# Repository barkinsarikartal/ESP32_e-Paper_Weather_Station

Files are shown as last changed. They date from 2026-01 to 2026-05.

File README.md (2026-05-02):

# ESP32 e-Paper Weather Station

A low-power, minimalist weather station powered by ESP32 and a Waveshare 1.54" e-Paper display. This project fetches real-time weather data from the OpenWeatherMap API and displays it on a crisp, tri-color (Red/Black/White) e-Ink screen.

<div align="center">
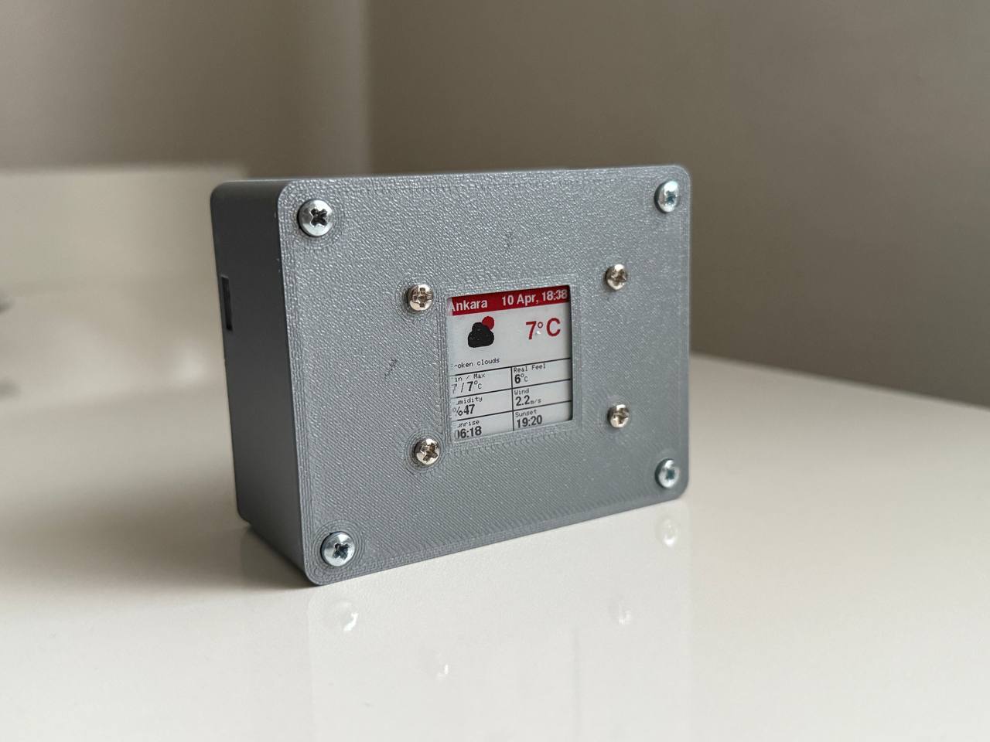
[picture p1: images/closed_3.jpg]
Project Showcase
  
</div>

## Features

* **Tri-Color Display:** Utilizes the red, black, and white capabilities of the Waveshare e-Paper module for a distinct, high-contrast UI.
* **Deep Sleep Power Saving:** The device wakes up, updates the screen, and immediately enters deep sleep to maximize battery life.
    * **Success Cycle:** Updates every 4 hours.
    * **Error Cycle:** Retries in 10 minutes if Wi-Fi or API fails (screen content is preserved to avoid displaying error messages permanently).
* **Comprehensive Data:** Displays City, Date, Time, Temperature, Weather Condition, Min/Max Temp, Real Feel, Humidity, Wind Speed, Sunrise, and Sunset times.
* **Custom Icons:** Includes custom-designed, pixel-perfect weather icons.

## Hardware Requirements

* **Microcontroller:** ESP32 (Tested on ESP32-WROOM-32U and Seeed Studio XIAO ESP32C3)
* **Display:** Waveshare 1.54inch e-Paper Module (B) V2 (SSD1680 Driver)
* **Connection:** SPI Interface

## Optional: 3D Printed Enclosure

To use this project with its custom 3D printed enclosure, you will need the following additional materials:
* **Charger IC:** TP4056 with Type-C Connection *(Not needed if using XIAO ESP32C3)*
* **Battery:** 18650 Li-ion Rechargable Battery (With a Single Cell Battery Holder)
* **Step-Up Boost Converter:** MT3608 Adjustable DC-DC Boost Power Converter *(Not needed if using XIAO ESP32C3)*
* **Hardware:** 4x M3x5.75 Brass Inserts, 4x M3 Screws Up to 8mm in Length

> **Note:** The brass inserts must be inserted into the 3D printed box using a soldering iron. Double-sided tape was used to secure the components inside the box.
> 
> **Important for XIAO ESP32C3 Users:** The XIAO ESP32C3 has a built-in battery charging circuit. You can connect your 18650 battery directly to the `BAT+` and `BAT-` pads on the bottom of the XIAO. Because of this, you do NOT need the TP4056 or MT3608 modules!
>
> **Battery Status:** There is currently no battery level measurement in this project. I started with a fully charged 1500 mAh 18650 battery. It lasted exactly a week with ESP32-WROOM-32U. I have not tested it with XIAO ESP32C3 yet. You can check if the battery is fully charged by observing the TP4056 LEDs visible through the Type-C port gap: when the red LED turns off and the blue LED turns on, the battery is fully charged.

The 3D models were designed using OpenSCAD with the help of Google Gemini. You can find the 3D files in the `/3D` folder of this repository, which includes:
* `box.scad` / `box.stl`: The main body/box of the enclosure.
* `lid.scad` / `lid.stl`: The front cover/lid of the enclosure.
* `print.3mf`: A ready-to-print project file containing both parts.

Alternatively, you can check them out and download them directly from [MakerWorld](https://makerworld.com/tr/models/2665507-weather-station-with-esp32-and-waveshare-e-paper#profileId-2949378).

Before Connecting Components to the 3D Box:
<div align="center">
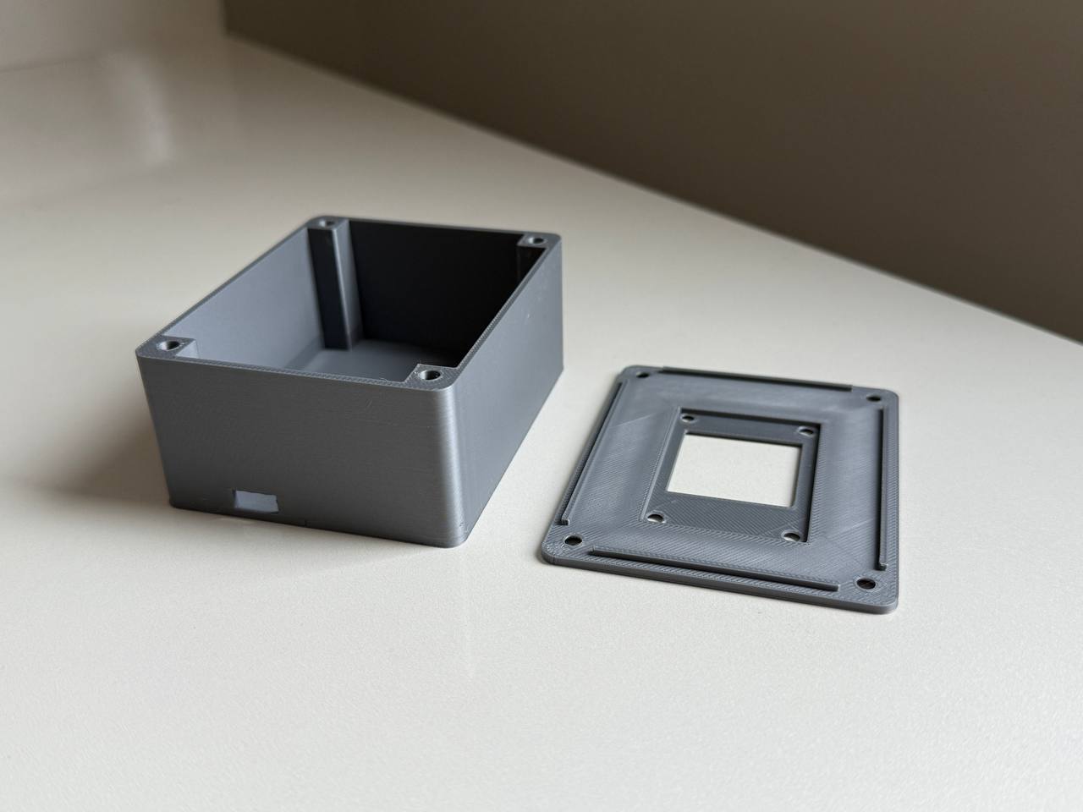
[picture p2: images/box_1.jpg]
  
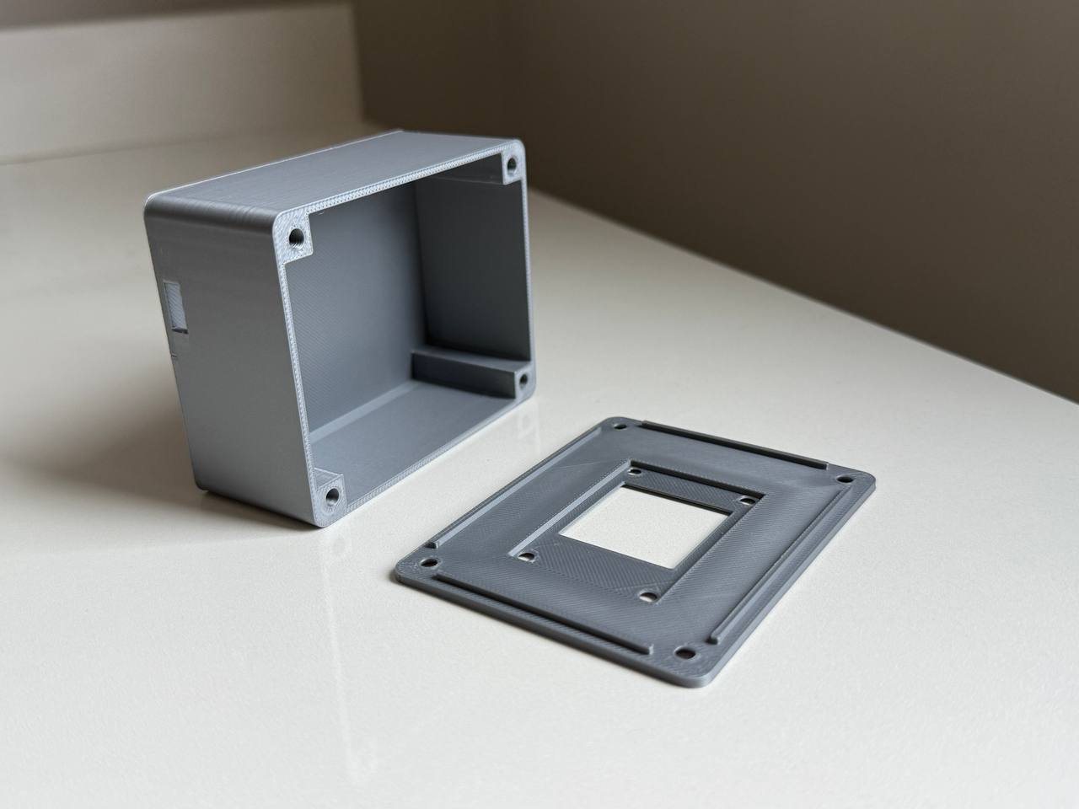
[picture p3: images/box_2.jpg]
  
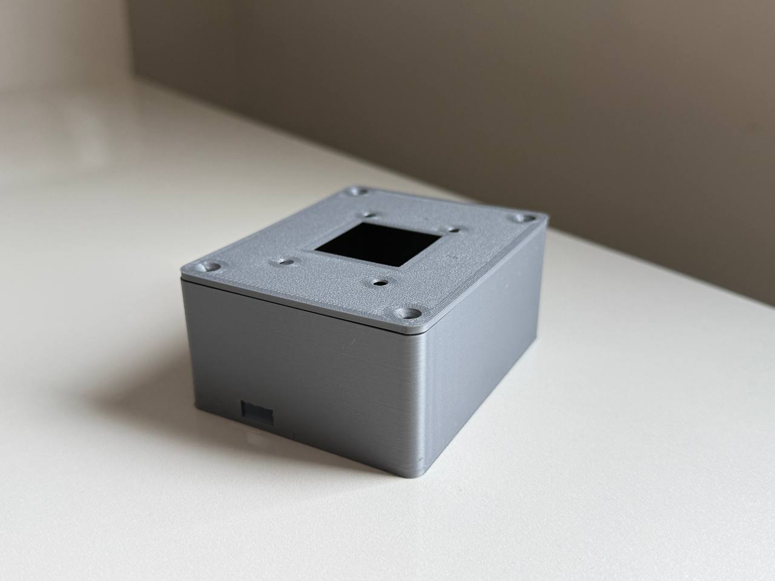
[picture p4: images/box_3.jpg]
  
</div>
<div align="center">
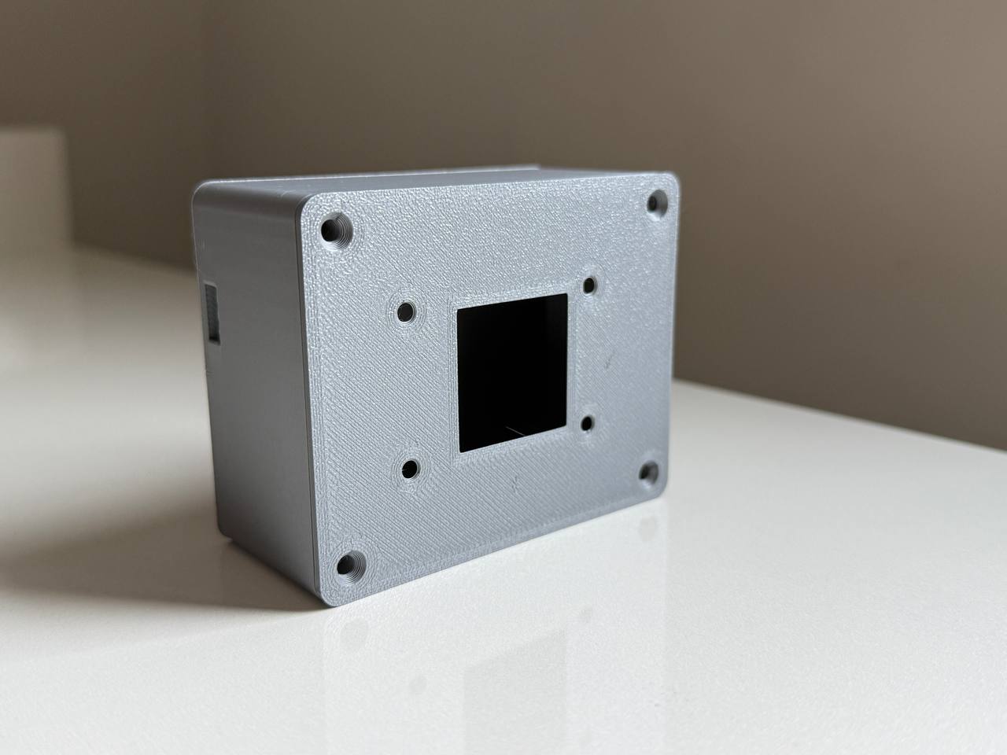
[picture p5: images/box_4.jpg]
  
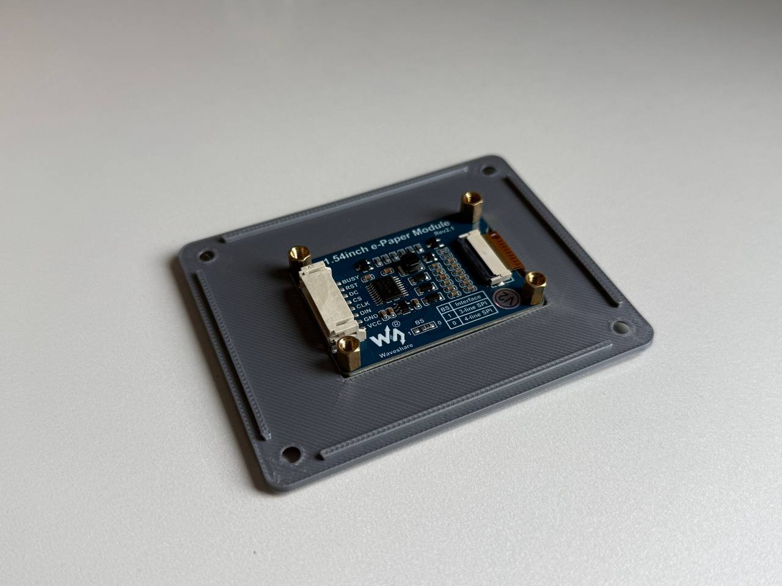
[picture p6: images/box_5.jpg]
  
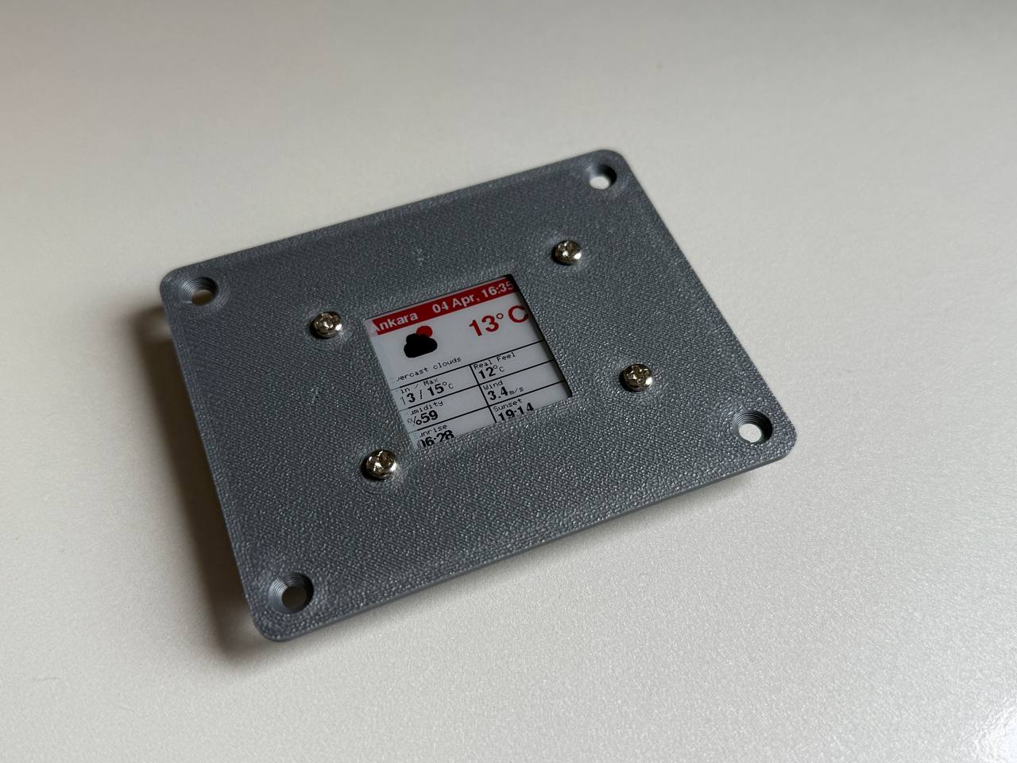
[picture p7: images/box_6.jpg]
  
</div>

<br>

After Connecting Components to the 3D Box:
<div align="center">
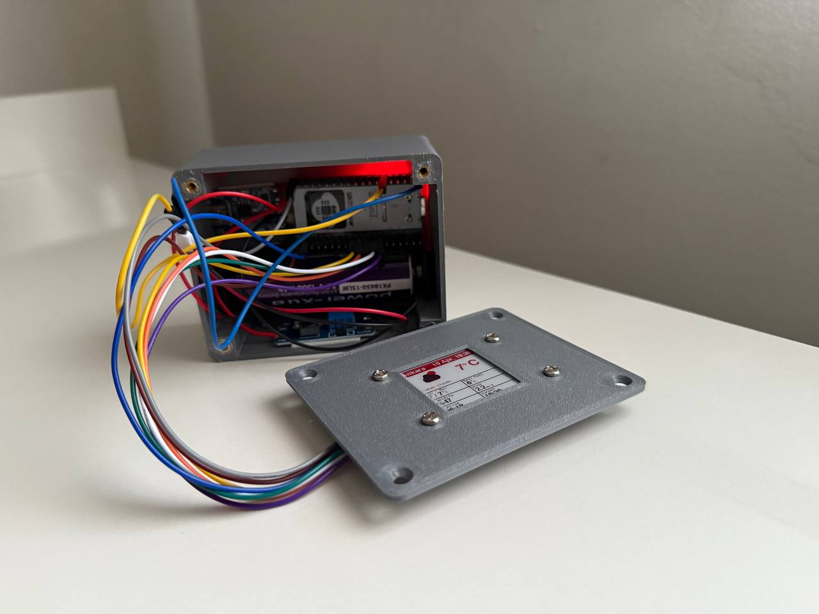
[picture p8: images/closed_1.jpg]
  
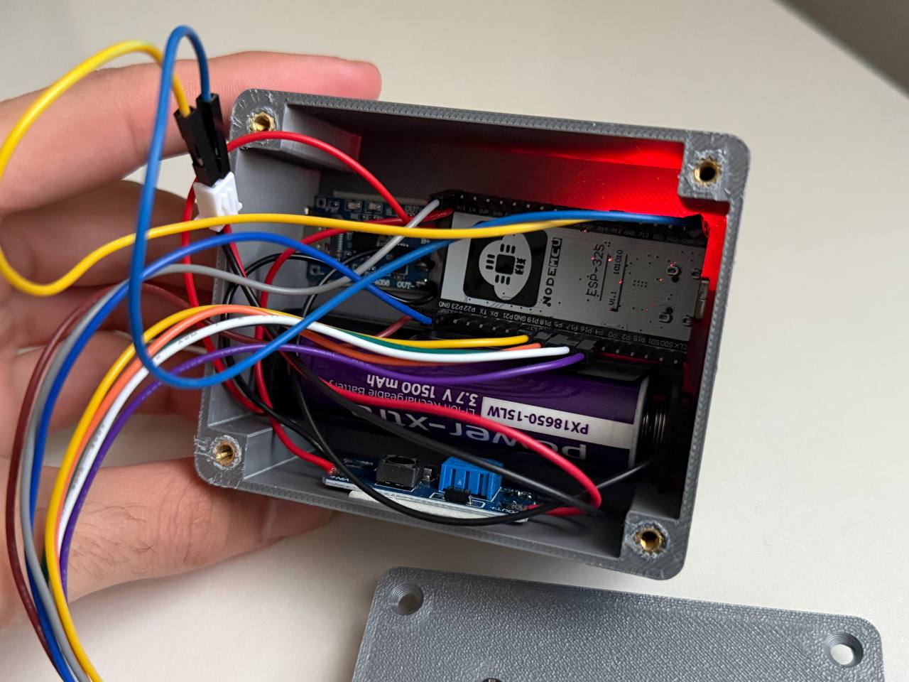
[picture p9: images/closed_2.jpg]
  
</div>
<div align="center">
  
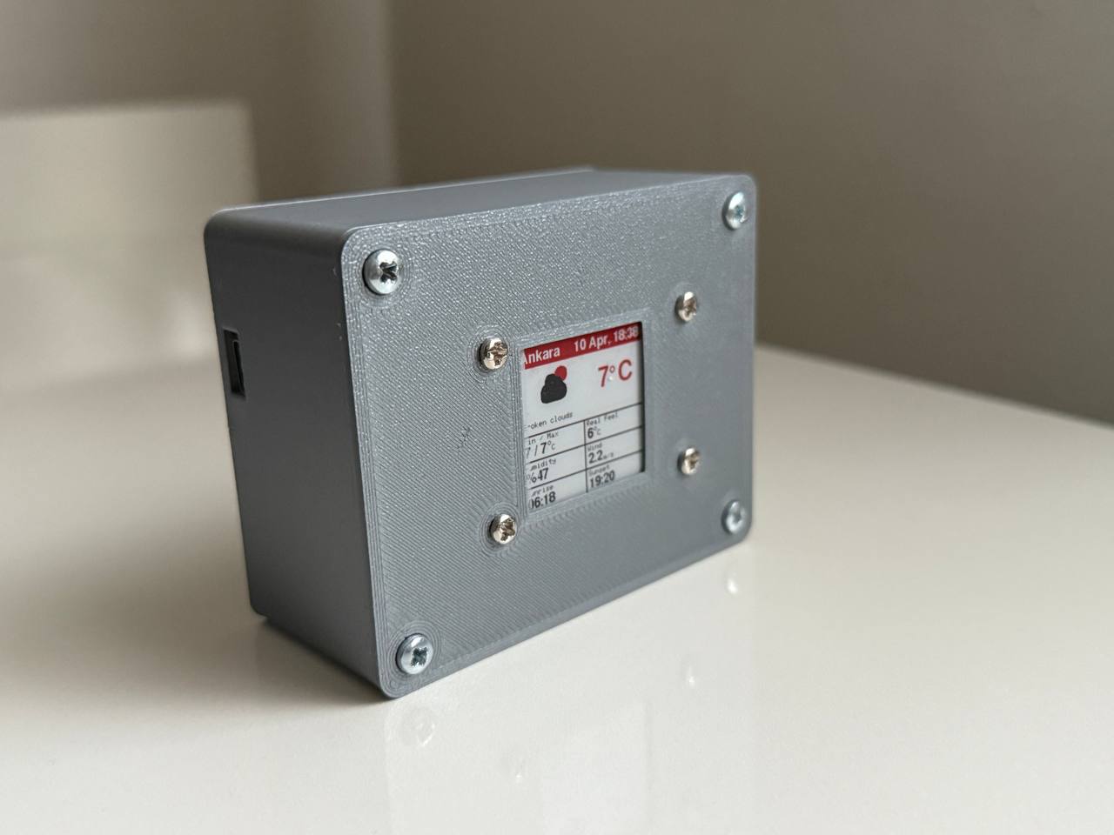
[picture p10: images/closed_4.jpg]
  
</div>

## Wiring Diagram

Connect the e-Paper HAT to your chosen microcontroller as defined in `config.h`. 

### Option A: ESP32-WROOM-32U

<div align="center">
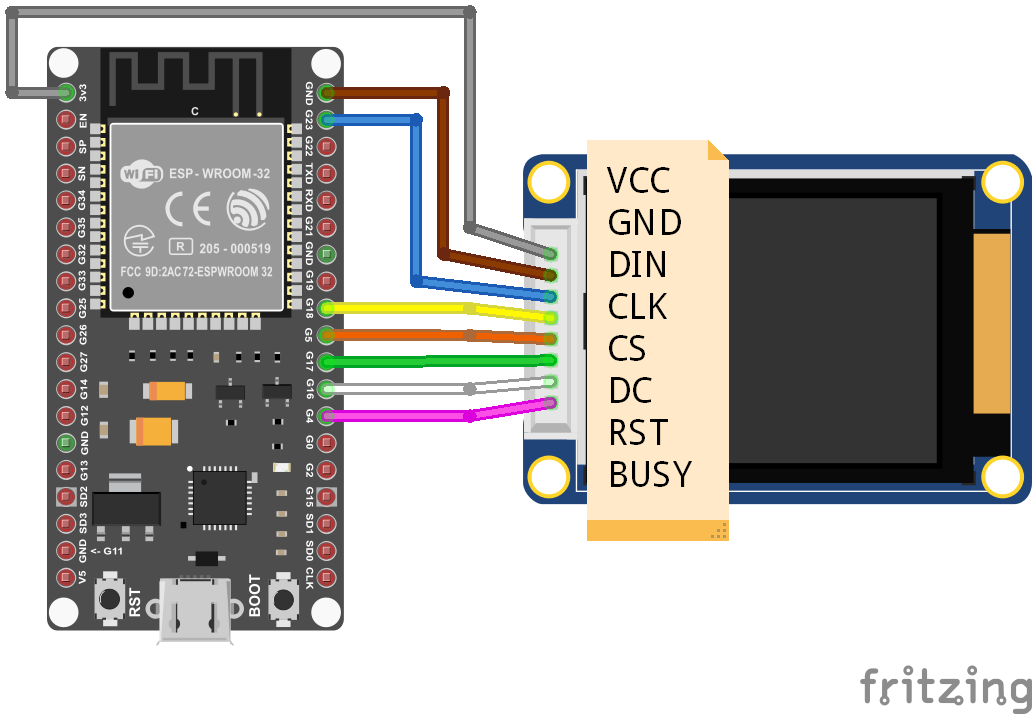
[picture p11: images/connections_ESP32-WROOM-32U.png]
ESP32-WROOM-32U Wiring Diagram
  
</div>

<br>

<div align="center">
  <table>
    <tr><th>e-Paper Pin</th><th>ESP32 Pin</th><th>Function</th></tr>
    <tr><td><b>VCC</b></td><td><b>3.3V</b></td><td>Power</td></tr>
    <tr><td><b>GND</b></td><td><b>GND</b></td><td>Ground</td></tr>
    <tr><td><b>DIN</b></td><td><b>GPIO 23</b></td><td>MOSI</td></tr>
    <tr><td><b>CLK</b></td><td><b>GPIO 18</b></td><td>SCK</td></tr>
    <tr><td><b>CS</b></td><td><b>GPIO 5</b></td><td>Chip Select</td></tr>
    <tr><td><b>DC</b></td><td><b>GPIO 17</b></td><td>Data/Cmd</td></tr>
    <tr><td><b>RST</b></td><td><b>GPIO 16</b></td><td>Reset</td></tr>
    <tr><td><b>BUSY</b></td><td><b>GPIO 4</b></td><td>Busy Status</td></tr>
  </table>
</div>

### Option B: Seeed Studio XIAO ESP32C3

<div align="center">
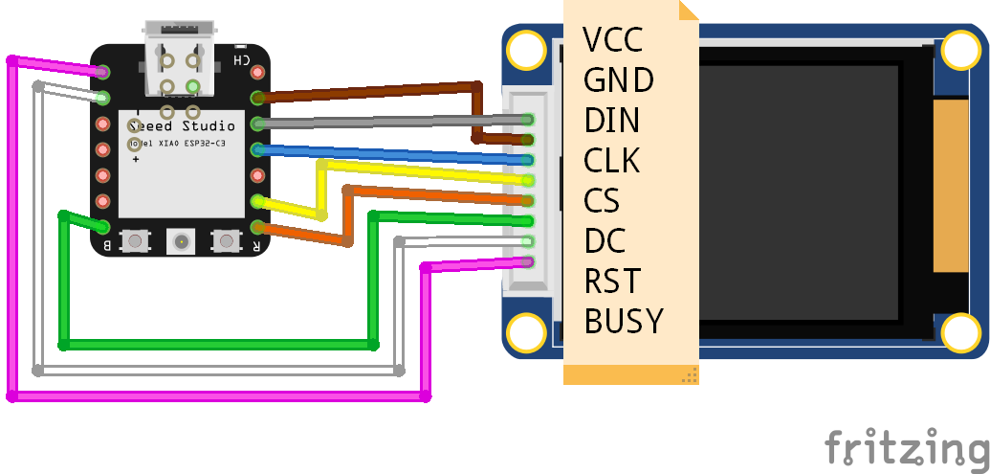
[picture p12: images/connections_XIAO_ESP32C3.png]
XIAO ESP32C3 Wiring Diagram
  
</div>

<br>

<div align="center">
  <table>
    <tr><th>e-Paper Pin</th><th>XIAO ESP32C3 Pin</th><th>Function</th></tr>
    <tr><td><b>VCC</b></td><td><b>3.3V</b></td><td>Power</td></tr>
    <tr><td><b>GND</b></td><td><b>GND</b></td><td>Ground</td></tr>
    <tr><td><b>DIN</b></td><td><b>GPIO 10 (D10)</b></td><td>MOSI</td></tr>
    <tr><td><b>CLK</b></td><td><b>GPIO 8 (D8)</b></td><td>SCK</td></tr>
    <tr><td><b>CS</b></td><td><b>GPIO 20 (D7)</b></td><td>Chip Select</td></tr>
    <tr><td><b>DC</b></td><td><b>GPIO 21 (D6)</b></td><td>Data/Cmd</td></tr>
    <tr><td><b>RST</b></td><td><b>GPIO 3 (D1)</b></td><td>Reset</td></tr>
    <tr><td><b>BUSY</b></td><td><b>GPIO 2 (D0)</b></td><td>Busy Status</td></tr>
  </table>
</div>

## Dependencies

This project requires the following Arduino libraries:

* **GxEPD2** by Jean-Marc Zingg (Display Driver)
* **Adafruit GFX Library** (Graphics Core)
* **ArduinoJson** by Benoit Blanchon (JSON Parsing)
* **HTTPClient** (Built-in ESP32 lib)
* **WiFi** (Built-in ESP32 lib)

## Configuration

1.  **Clone the repository:**
    ```bash
    git clone https://github.com/barkinsarikartal/ESP32_e-Paper_Weather_Station.git
    ```
2.  **Select Your Board:** Open `ESP32_e-Paper_Weather_Station.ino` and uncomment the board you are using at the top of the file:
    ```cpp
    // #define BOARD_ESP32_DEVKIT
    // #define BOARD_XIAO_ESP32C3
    ```
3.  **Update Credentials:** Open `config.h` and update your Wi-Fi and OpenWeatherMap details:
    ```cpp
    // config.h
    const char* WIFI_SSID = "YOUR_WIFI_SSID";
    const char* WIFI_PASS = "YOUR_WIFI_PASSWORD";
    
    // Get your free API key from https://openweathermap.org/
    String OPENWEATHER_URL = "https://api.openweathermap.org/data/2.5/weather?q=CITY,COUNTRY&units=metric&appid=YOUR_API_KEY"; 
    ```
4.  **Upload:** Connect your ESP32 via USB and upload the code using the Arduino IDE.

## File Structure

* `ESP32_e-Paper_Weather_Station.ino`: Main application logic, deep sleep management, UI rendering, and board selection.
* `config.h`: Configuration file for Wi-Fi credentials, API endpoints, pin definitions, and sleep timers.
* `bitmaps.h`: Contains byte arrays for the custom weather icons (Sun, Clouds, Rain, Snow, etc.).
* `sketch_ESP32-WROOM-32U.fzz` & `sketch_XIAO_ESP32C3.fzz`: Fritzing wiring diagrams for both boards.

## Power Consumption Logic

To ensure longevity, the code implements a "Silent Fail" mechanism:
* **If Data Fetched:** The screen updates, and the ESP32 sleeps for **4 hours**.
* **If Connection Fails:** The screen **is not updated** (preserving the last known good weather data), and the ESP32 sleeps for only **10 minutes** before retrying.

## License

This project is open-source and available under the MIT License.

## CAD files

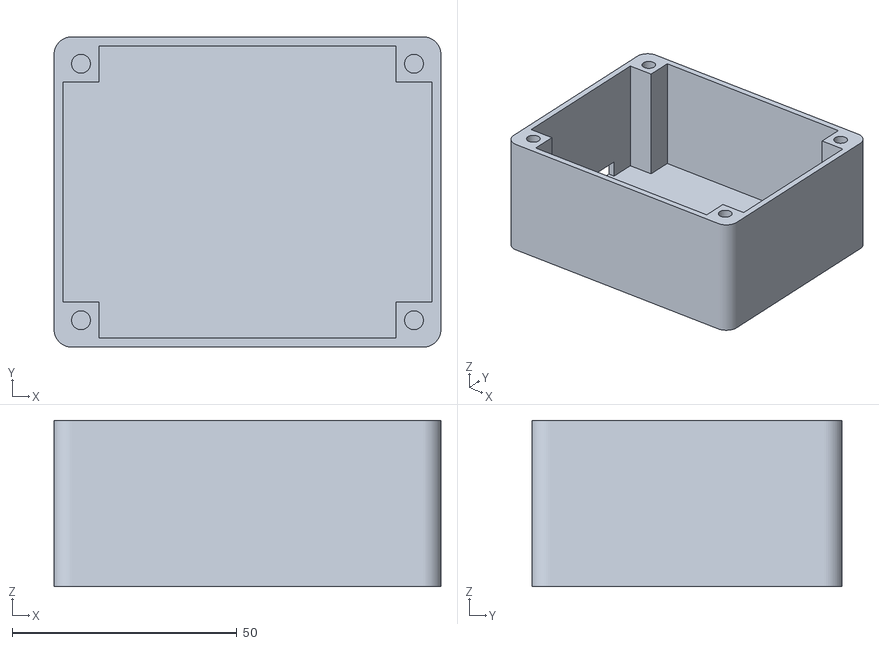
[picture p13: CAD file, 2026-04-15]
3D/box.stl
86.0 x 69.0 x 37.0

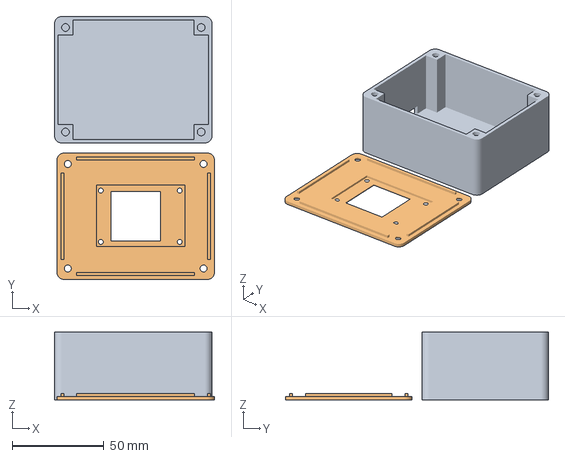
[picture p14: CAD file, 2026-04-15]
3D/print.3mf
87.3 x 143.4 x 37.0 mm
box.stl
lid.stl

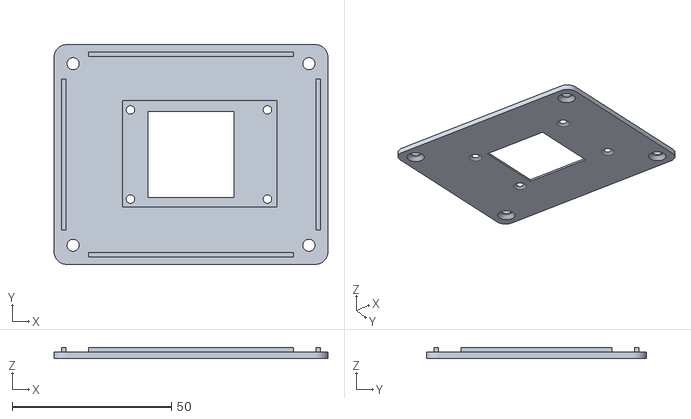
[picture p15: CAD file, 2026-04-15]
3D/lid.stl
86.0 x 69.0 x 3.50

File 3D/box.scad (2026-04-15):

// --- PARAMETRELER ---
$fn = 60;
wall = 2.0;
internal_w = 82;
internal_h = 65;
internal_d = 35;
clearance = 0.5;
box_radius = 4.0;

// Kılavuz Kenarı (Lip) Parametreleri
lip_height = 1.5;     // Kapağın içine doğru giren çıkıntı
lip_clearance = 0.3;  // Rahat geçmesi için bırakılan tolerans

// Köşe Sütunları
pillar_s = 8;
insert_dia = 4.2;
insert_depth = 8; 

// Ekran Montajı (Waveshare 1.54")
disp_pcb_w = 48;
disp_pcb_h = 33;
disp_pattern_x = 43;
disp_pattern_y = 28;

// Delik Çapları
disp_screw_hole = 0.0; // M3 vidanın geçmesi için
disp_countersink = 5.0; // M3 vida başı için

// --- YARDIMCI MODÜL: Yuvarlatılmış Dikdörtgen ---
module rounded_box(w, h, d, r) {
    hull() {
        translate([r, r, 0]) cylinder(r=r, h=d);
        translate([w-r, r, 0]) cylinder(r=r, h=d);
        translate([r, h-r, 0]) cylinder(r=r, h=d);
        translate([w-r, h-r, 0]) cylinder(r=r, h=d);
    }
}

module body() {
    difference() {
        // Dış Kabuk (Yuvarlatılmış)
        rounded_box(internal_w + 2*wall, internal_h + 2*wall, internal_d + wall, box_radius);
        
        translate([wall, wall, wall])
            rounded_box(internal_w, internal_h, internal_d + 1, box_radius - wall);
        
        // USB-C Kesimi
        translate([-1, 39 + wall, wall])
            cube([wall + 2, 10, 5]);
    }

    for(pos = [[wall, wall], 
               [internal_w + wall - pillar_s, wall], 
               [internal_w + wall - pillar_s, internal_h + wall - pillar_s], 
               [wall, internal_h + wall - pillar_s]]) {
        translate([pos[0], pos[1], wall])
        difference() {
            cube([pillar_s, pillar_s, internal_d]);
            translate([pillar_s/2, pillar_s/2, internal_d - insert_depth])
                cylinder(d=insert_dia, h=insert_depth + 1);
        }
    }
}

body();

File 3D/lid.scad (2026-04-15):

// --- PARAMETRELER ---
$fn = 60;
wall = 2.0;
internal_w = 82;
internal_h = 65;
internal_d = 35;
clearance = 0.5;
box_radius = 4.0;

// Kılavuz Kenarı (Lip) Parametreleri
lip_height = 1.5;     // Kapağın içine doğru giren çıkıntı
lip_clearance = 0.3;  // Rahat geçmesi için bırakılan tolerans

// Köşe Sütunları
pillar_s = 8;
insert_dia = 4.2;
insert_depth = 8; 

// Ekran Montajı (Waveshare 1.54")
disp_pcb_w = 48;
disp_pcb_h = 33;
disp_pattern_x = 43;
disp_pattern_y = 28;

// Delik Çapları
disp_screw_hole = 0.0; // M3 vidanın geçmesi için
disp_countersink = 5.0; // M3 vida başı için

// --- YARDIMCI MODÜL: Yuvarlatılmış Dikdörtgen ---
module rounded_box(w, h, d, r) {
    hull() {
        translate([r, r, 0]) cylinder(r=r, h=d);
        translate([w-r, r, 0]) cylinder(r=r, h=d);
        translate([r, h-r, 0]) cylinder(r=r, h=d);
        translate([w-r, h-r, 0]) cylinder(r=r, h=d);
    }
}

module lid() {
    window_size = 27;
    // Pencere konumu
    win_x = (internal_w + 2*wall - window_size) / 2;
    win_y = (internal_h + 2*wall - window_size) / 2;

    // Ekranın PCB'sinin oturacağı toplam alan (Gömme alanı)
    pocket_w = disp_pcb_w + 0.5;
    pocket_h = disp_pcb_h + 0.5;
    // PCB'nin kapağa göre konumu (Offsetler dahil)
    pocket_x = win_x - 8; 
    pocket_y = win_y - 3;
    
    standoff_base_x = win_x - 8 + (disp_pcb_w - disp_pattern_x)/2;
    standoff_base_y = win_y - 3 + (disp_pcb_h - disp_pattern_y)/2;

    difference() {
        // Ana Kapak Plakası
        rounded_box(internal_w + 2*wall, internal_h + 2*wall, wall, box_radius);
        
        translate([pocket_x, pocket_y, wall - 1.3])
            cube([pocket_w, pocket_h, 1.4]);

        // Ekran Penceresi (Dışarıya açılan delik)
        translate([win_x, win_y, -1])
            cube([window_size, window_size, wall + 2]);
        
        // Havşalı Vida Delikleri (M3)
        for(pos = [[wall + pillar_s/2, wall + pillar_s/2], 
                   [internal_w + wall - pillar_s/2, wall + pillar_s/2], 
                   [internal_w + wall - pillar_s/2, internal_h + wall - pillar_s/2], 
                   [wall + pillar_s/2, internal_h + wall - pillar_s/2]]) {
            translate([pos[0], pos[1], -1]) {
                cylinder(d=3.8, h=wall + 2);
                translate([0,0, 0.9]) 
                    cylinder(d1=7.0, d2=3.8, h=1.5);
            }
        }
        
        // Ekran Sabitleme Vidaları (Dışarıdan atılacak delikler)
        for(x = [0, disp_pattern_x], y = [0, disp_pattern_y]) {
            translate([standoff_base_x + x, standoff_base_y + y, -1]) {
                // Vida geçiş deliği
                cylinder(d=disp_screw_hole, h=wall + 2);
                // Dış yüzeydeki havşa deliği (Vida başı sıfır olması için)
                translate([0, 0, 1.0]) 
                    cylinder(d1=disp_countersink, d2=disp_screw_hole, h=1.5);
            }
        }
    }
    
    // Kılavuz Kenarı
    translate([wall + lip_clearance, wall + lip_clearance, wall])
    difference() {
        // Ana Kılavuz Çerçevesi
        rounded_box(internal_w - 2*lip_clearance, internal_h - 2*lip_clearance, lip_height, box_radius - wall - lip_clearance);
        
        // Çerçevenin içini boşalt (Sadece bir kenar kalsın)
        translate([1.5, 1.5, -1])
            rounded_box(internal_w - 2*lip_clearance - 3, internal_h - 2*lip_clearance - 3, lip_height + 2, box_radius - wall - lip_clearance - 1.5);
            
        // Köşe Sütunları için Boşluklar (Kılavuz kenarı sütunlara çarpmamalı)
        pillar_clearance = 0.5;
        for(pos = [[-1, -1], 
                   [internal_w - pillar_s - 2*lip_clearance - pillar_clearance, -1], 
                   [internal_w - pillar_s - 2*lip_clearance - pillar_clearance, internal_h - pillar_s - 2*lip_clearance - pillar_clearance], 
                   [-1, internal_h - pillar_s - 2*lip_clearance - pillar_clearance]]) {
            translate([pos[0], pos[1], -0.1])
                cube([pillar_s + pillar_clearance + 1, pillar_s + pillar_clearance + 1, lip_height + 1]);
        }
    }

}

lid();

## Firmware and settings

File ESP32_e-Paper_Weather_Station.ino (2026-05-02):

/**
 * ESP32 e-Paper Weather Station
 * Hardware: ESP32-WROOM-32U + Waveshare 1.54" V2 (SSD1680)
 * Source: OpenWeatherMap API
 * Notes: Please do not forget to change WiFi Credentials and OpenWeather API URL from config.h
 */

// Select a board for your project. Remove the // symbol at the beginning of the board you are using:
// #define BOARD_ESP32_DEVKIT
// #define BOARD_XIAO_ESP32C3

#include <GxEPD2_3C.h>
#include <Fonts/FreeSansBold9pt7b.h>
#include <Fonts/FreeSansBold12pt7b.h>
#include <Fonts/FreeSansBold18pt7b.h>
#include <WiFi.h>
#include <HTTPClient.h>
#include <ArduinoJson.h>
#include <time.h>

#include "config.h"
#include "bitmaps.h"

// Display Constructor for Waveshare 1.54" V2 (https://www.waveshare.com/1.54inch-e-paper-module-b.htm)
GxEPD2_3C<GxEPD2_154_Z90c, GxEPD2_154_Z90c::HEIGHT> display(GxEPD2_154_Z90c(EPD_CS, EPD_DC, EPD_RST, EPD_BUSY));

// Data Holders
String cityName, country, weatherDesc, iconCode;
float temp, feelsLike, tempMin, tempMax, windSpeed;
int humidity;
long dt, sunrise, sunset;
int timezone;
bool dataFetched = false;

// Function Prototypes
void fetchWeatherData();
void drawDashboardUI();
void drawLabelValue(int x, int y, String label, String value);
void drawOWMIcon(String code, int x, int y, int h, int w);
String getFormattedTime(long unixTime, int timezoneOffset);
String getFormattedDate(long unixTime, int timezoneOffset);

void setup() {
  Serial.begin(115200);
  
  // 1. Connect to WiFi
  // We try to connect. If it fails, we won't even turn on the display.
  WiFi.begin(WIFI_SSID, WIFI_PASS);
  int timeout = 0;
  Serial.print("Connecting to WiFi");
  while (WiFi.status() != WL_CONNECTED && timeout < 20) {
    delay(500);
    Serial.print(".");
    timeout++;
  }
  Serial.println();
  
  // 2. Try Fetching Data
  if (WiFi.status() == WL_CONNECTED) {
    Serial.println("WiFi connected. Fetching data...");
    fetchWeatherData();

    // Disconnect WiFi to save power immediately after fetching
    WiFi.disconnect(true);
    WiFi.mode(WIFI_OFF);
  }
  else {
    Serial.println("WiFi connection failed.");
  }

  // 3. Decision Logic
  uint64_t sleepTimer;
  
  if (dataFetched) {
    Serial.println("Data fetched successfully. Updating display.");

    SPI.begin(SPI_SCK, SPI_MISO, SPI_MOSI, EPD_CS);
    display.init(115200);
    display.setRotation(1);

    drawDashboardUI();

    display.powerOff();

    sleepTimer = SLEEP_DURATION_OK; // 4 Hours
  }
  else {
    Serial.println("Failed to fetch data. Keeping old screen content.");
    Serial.println("Going to short sleep.");

    // The e-Paper will keep showing whatever was on it before (the old weather data).
    sleepTimer = SLEEP_DURATION_ERROR; // 10 Minutes
  }

  // 4. Enter Deep Sleep
  Serial.printf("Entering deep sleep for %llu microseconds...\n", sleepTimer);
  esp_sleep_enable_timer_wakeup(sleepTimer);
  esp_deep_sleep_start();
}

void loop() {
  //empty loop - unreachable
  Serial.println("if you are seeing this on serial monitor, something went wrong...");
  delay(1000);
}

void fetchWeatherData() {
  HTTPClient http;
  http.begin(OPENWEATHER_URL);
  int httpCode = http.GET();

  if (httpCode > 0) {
    String payload = http.getString();
    Serial.println(payload);
    DynamicJsonDocument doc(2048);
    DeserializationError error = deserializeJson(doc, payload);

    if (!error) {
      cityName = doc["name"].as<String>();
      weatherDesc = doc["weather"][0]["description"].as<String>();
      iconCode = doc["weather"][0]["icon"].as<String>();
      country = doc["sys"]["country"].as<String>();
      
      temp = doc["main"]["temp"];
      feelsLike = doc["main"]["feels_like"];
      tempMin = doc["main"]["temp_min"];
      tempMax = doc["main"]["temp_max"];
      humidity = doc["main"]["humidity"];
      windSpeed = doc["wind"]["speed"];
      
      dt = doc["dt"];
      sunrise = doc["sys"]["sunrise"];
      sunset = doc["sys"]["sunset"];
      timezone = doc["timezone"];
      
      if (weatherDesc.length() > 0) {
        weatherDesc.setCharAt(0, toupper(weatherDesc.charAt(0)));
      }
      
      dataFetched = true;
    }
    else {
      Serial.print("JSON Error: "); Serial.println(error.c_str());
    }
  }
  else {
    Serial.printf("HTTP Error: %s\n", http.errorToString(httpCode).c_str());
  }
  http.end();
}

void drawDashboardUI() {
  display.setFullWindow();
  display.firstPage();
  do {
    display.fillScreen(GxEPD_WHITE);

    // Header
    display.fillRect(0, 0, 200, 25, GxEPD_RED);
    display.setTextColor(GxEPD_WHITE);
    display.setFont(&FreeSansBold9pt7b);
    display.setCursor(5, 18);
    display.print(cityName);

    String dateStr = getFormattedDate(dt, timezone);
    String timeStr = getFormattedTime(dt, timezone);
    String headerRight = dateStr + ", " + timeStr;

    int16_t x1, y1; uint16_t w, h;
    display.getTextBounds(headerRight, 0, 0, &x1, &y1, &w, &h);
    display.setCursor(200 - w - 5, 18);
    display.print(headerRight);

    // Main Icon & Temp
    drawOWMIcon(iconCode, 18, 19, 75, 75);

    display.setTextColor(GxEPD_RED);
    display.setFont(&FreeSansBold18pt7b);
    String tempNum = String((int)temp);
    display.getTextBounds(tempNum, 0, 0, &x1, &y1, &w, &h);
    int centerX = 90 + (110 - w) / 2; 
    display.setCursor(centerX - 10, 70);
    display.print(tempNum);
    
    // Manual Degree Symbol and "C"
    int circleX = display.getCursorX() + 5;
    int circleY = 70 - 18;
    display.drawCircle(circleX, circleY, 4, GxEPD_RED);
    display.drawCircle(circleX, circleY, 3, GxEPD_RED);
    display.setCursor(circleX + 10, 70);
    display.print("C");

    display.setTextColor(GxEPD_BLACK);
    display.setFont(NULL);
    display.setCursor(5, 90); 
    display.print(weatherDesc);

    // Grid
    display.fillRect(0, 105, 200, 2, GxEPD_BLACK);
    display.fillRect(0, 136, 200, 2, GxEPD_BLACK);
    display.fillRect(0, 168, 200, 2, GxEPD_BLACK);
    display.fillRect(100, 105, 2, 95, GxEPD_BLACK);

    display.setTextColor(GxEPD_BLACK);
    drawLabelValue(5, 108, "Min / Max", String((int)tempMin) + " / " + String((int)tempMax));
    drawLabelValue(105, 108, "Real Feel", String((int)feelsLike));
    drawLabelValue(5, 140, "Humidity", "%" + String(humidity));
    drawLabelValue(105, 140, "Wind", String(windSpeed, 1));
    drawLabelValue(5, 172, "Sunrise", getFormattedTime(sunrise, timezone));
    drawLabelValue(105, 172, "Sunset", getFormattedTime(sunset, timezone));
  }
  while (display.nextPage());
}

void drawLabelValue(int x, int y, String label, String value) {
  display.setFont(NULL);
  display.setCursor(x, y); display.print(label);
  display.setFont(&FreeSansBold9pt7b);
  int yValue = y + 22;
  display.setCursor(x, yValue); display.print(value);
  
  // Degree Symbol and "C" for Real Feel
  if(label == "Real Feel") {
    int cx = display.getCursorX() + 3;
    int cy = yValue - 10;
    display.drawCircle(cx, cy, 2, GxEPD_BLACK);
    display.setFont(NULL);
    display.setCursor(cx + 4, yValue - 7);
    display.print("C");
  }
  
  // Degree Symbol and "C" for Min/Max
  else if(label == "Min / Max") {
    int cx = display.getCursorX() + 3;
    int cy = yValue - 10;
    display.drawCircle(cx, cy, 2, GxEPD_BLACK);
    display.setFont(NULL);
    display.setCursor(cx + 4, yValue - 7);
    display.print("C");
  }

  // Unit for Wind
  else if(label == "Wind") {
    display.setFont(NULL);
    display.setCursor(display.getCursorX() + 2, yValue - 5);
    display.print("m/s");
  }
}

String getFormattedTime(long unixTime, int timezoneOffset) {
  time_t localTime = unixTime + timezoneOffset; 
  struct tm * ti = gmtime(&localTime);
  char buffer[6];
  sprintf(buffer, "%02d:%02d", ti->tm_hour, ti->tm_min);
  return String(buffer);
}

String getFormattedDate(long unixTime, int timezoneOffset) {
  time_t localTime = unixTime + timezoneOffset;
  struct tm * ti = gmtime(&localTime);
  char buffer[10];
  strftime(buffer, sizeof(buffer), "%d %b", ti);
  return String(buffer);
}

void drawOWMIcon(String code, int x, int y, int h, int w) { // based on https://openweathermap.org/weather-conditions
  bool isNight = (code.indexOf('n') != -1);
  String mainCode = code.substring(0, 2);

  if (mainCode == "01") { // Clear Sky
    if (isNight) display.drawBitmap(x, y, moon, h, w, GxEPD_BLACK);
    else display.drawBitmap(x, y, sun, h, w, GxEPD_RED);
  }
  else if (mainCode == "02" || mainCode == "03" || mainCode == "04") { // Few/Scattered/Broken Clouds
    if (!isNight){
      display.drawBitmap(x, y, clouds, h, w, GxEPD_BLACK);
      display.drawBitmap(x, y, sun_over_clouds, h, w, GxEPD_RED);
    }
    else {
      display.drawBitmap(x, y, clouds, h, w, GxEPD_BLACK);
      display.drawBitmap(x, y, moon_over_clouds, h, w, GxEPD_BLACK);
    }
  } 
  else if (mainCode == "09" || mainCode == "10") { // Rain
    display.drawBitmap(x, y, rainy, h, w, GxEPD_BLACK);
  } 
  else if (mainCode == "11") { // Thunderstorm
    display.drawBitmap(x, y, thunder, h, w, GxEPD_BLACK);
  } 
  else if (mainCode == "13") { // Snow
    display.drawBitmap(x, y, snow, 50, 50, GxEPD_BLACK);
  } 
  else if (mainCode == "50") { // Mist
    display.drawBitmap(x, y, fog, h, w, GxEPD_BLACK);
  }
  else { // Unknown
    display.drawCircle(x, y, 15, GxEPD_BLACK);
    display.setCursor(x-5, y+5); display.print("?");
  }
}

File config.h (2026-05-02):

#ifndef CONFIG_H
#define CONFIG_H

// --- Wi-Fi Credentials ---
const char* WIFI_SSID = "WIFI_SSID";
const char* WIFI_PASS = "WIFI_PASS";

// --- OpenWeatherMap Settings ---
// Zip code is generally more accurate than city name alone
// More information at: https://openweathermap.org/current

// For zip code queries
// ZZZZZ = Zip Code, CC = Country (e.g. TR, GB), ABCDEFGHIJKLMNOPQRSTUVWXYZ= = Your API Key
// String OPENWEATHER_URL = "https://api.openweathermap.org/data/2.5/weather?zip=ZZZZZ,CC&units=metric&appid=ABCDEFGHIJKLMNOPQRSTUVWXYZ";

// For city queries
// AAA = City (e.g. Ankara, London), CC = Country (e.g. TR, GB), ABCDEFGHIJKLMNOPQRSTUVWXYZ= = Your API Key
String OPENWEATHER_URL = "https://api.openweathermap.org/data/2.5/weather?q=AAA,CC&units=metric&appid=ABCDEFGHIJKLMNOPQRSTUVWXYZ";

// --- Pin Definitions (ESP32 -> Waveshare e-Paper Driver Hat) ---
#if defined(BOARD_ESP32_DEVKIT)
  // NodeMCU-ESP32S / ESP32-WROOM-32U
  #define EPD_CS    5
  #define EPD_DC    17
  #define EPD_RST   16
  #define EPD_BUSY  4
  #define SPI_SCK   18
  #define SPI_MISO  19
  #define SPI_MOSI  23

#elif defined(BOARD_XIAO_ESP32C3)
  // Seeed Studio XIAO ESP32-C3
  #define EPD_CS    20   // D7
  #define EPD_DC    21   // D6
  #define EPD_RST   3    // D1
  #define EPD_BUSY  2    // D0
  #define SPI_SCK   8    // D8
  #define SPI_MISO  9    // D9
  #define SPI_MOSI  10   // D10

#else
  #error "No board selected! Select a BOARD_ definition in the config.h file."
#endif

// --- Sleep Intervals (in microseconds) ---
// 4 Hours = 4 * 60 * 60 * 1,000,000
const uint64_t SLEEP_DURATION_OK = 14400000000ULL;
// 10 Minutes = 10 * 60 * 1,000,000
const uint64_t SLEEP_DURATION_ERROR = 600000000ULL;

#endif

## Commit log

2026-01-25 Add ESP32 e-Paper weather station project files
    Initial commit of the ESP32 e-Paper Weather Station, including the main Arduino sketch, configuration header, weather icon bitmaps, a wiring diagram image, and a Fritzing schematic.
    The project fetches weather data from OpenWeatherMap and displays it on a Waveshare 1.54" e-Paper display.
    [sketch.fzz]
2026-01-30 Adjust weather description font and position in UI
    For long weather descriptions, string was not fitting to a single row, so I set the weather description font to default and moved its position up by 10 pixels in the dashboard UI. Also updated the showcase image.
    [ESP32_e-Paper_Weather_Station.ino]
2026-04-15 Added 3D enclosure models, images, and update README
    - Added /3D directory containing enclosure and lid models (SCAD, STL, 3MF).
    - Added /images directory with detailed pre/post-assembly photos.
    - Updated README.md
    [box.scad, box.stl, lid.scad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]
2026-05-02 Add board selection and Xiao ESP32-C3 pinmap
    - Introduce selectable board macros and add pin mappings for Seeed XIAO ESP32-C3 and ESP32 DevKit.
    - Replace hardcoded PIN_* defines with EPD_* names, update the e-paper display constructor to use EPD_* constants, and initialize SPI with explicit pins (SPI.begin(...)) before display.init().
    - Also add a compile-time #error if no board is selected.
    These changes enable multi-board support and correct SPI/pin wiring for the XIAO ESP32-C3.
    [ESP32_e-Paper_Weather_Station.ino, config.h]
2026-05-02 Add XIAO ESP32C3 docs and wiring diagrams
    Update README to add support for Seeed Studio XIAO ESP32C3
    [sketch_ESP32-WROOM-32U.fzz, sketch_XIAO_ESP32C3.fzz]
